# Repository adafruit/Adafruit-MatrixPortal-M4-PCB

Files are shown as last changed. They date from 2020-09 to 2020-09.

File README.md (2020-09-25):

## Adafruit MatrixPortal M4 - CircuitPython Powered Internet Display PCB

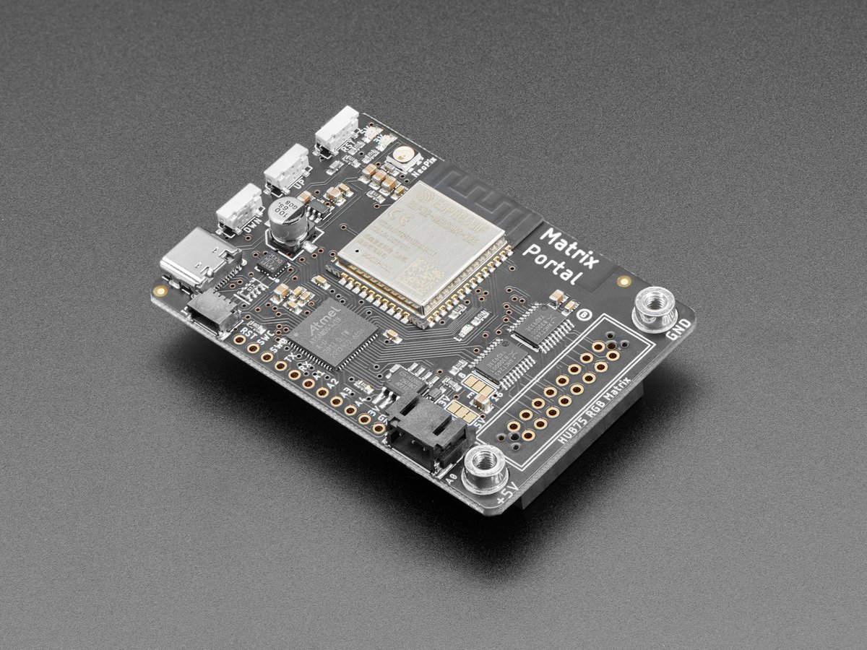
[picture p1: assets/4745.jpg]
<a href="http://www.adafruit.com/products/4745"><br/>
Click here to purchase one from the Adafruit shop</a>

PCB files for the Adafruit MatrixPortal M4 - CircuitPython Powered Internet Display. 

Format is EagleCAD schematic and board layout
* https://www.adafruit.com/product/4745

### Description

Folks love our [wide selection of RGB matrices](https://www.adafruit.com/category/327) and accessories, for making custom colorful LED displays... and our RGB Matrix Shields and FeatherWings can be quickly soldered together to make the wiring much easier. But what if we made it even easier than that? **Like, no solder, no wiring, just instant plug-and-play?** Dream no more - with the **Adafruit Matrix Portal add-on for RGB Matrices**, there's never been an easier way to create powerful Internet-connected LED displays.

Plug directly into the back of [any HUB-75 compatible display (all the ones we stock will work) from 16x32 up to 64x64](https://www.adafruit.com/category/327)! Use the included screws to attach the power cable to the power plugs with a common screwdriver, then power it with any USB C power supply. (For larger projects, power the matrices with a separate 5V power adapter)

Then code up your project in [CircuitPython](https://learn.adafruit.com/rgb-led-matrices-matrix-panels-with-circuitpython) or [Arduino](https://learn.adafruit.com/adafruit-protomatter-rgb-matrix-library), our Protomatter matrix library works great on the SAMD51 chipset, knowing that you've got the wiring and level shifting all handled. Here's what you get:

 * **ATSAMD51J19 Cortex M4 processor**, 512KB flash, 192K of SRAM, with full Arduino or CircuitPython support
 * **ESP32 WiFi co-processor** with TLS support and SPI interface to the M4, with full Arduino or CircuitPython support
 * **USB Type C** connector for data and power connectivity
 * [**I2C STEMMA QT connector** for plug-n-play use of any of our STEMMA QT devices or sensors](https://www.adafruit.com/category/620) can also be used with [any Grove I2C devices using this adapter cable](https://www.adafruit.com/product/4528))
 * **JST 3-pin connector** that also has analog input/output, say for adding audio playback to projects
 * **LIS3DH accelerometer** for digital sand projects or detecting taps/orientation.
 * **GPIO breakouts** including 4 analog outputs with PWM and SPI support for adding other hardware.
 * **Address E line jumper** for use with 64x64 matrices (check your matrix to see which pin is used for address E!
 * **Two user interface buttons** + one reset button
 * **Indicator NeoPixel** and red LED
 * **Green power indicator LEDs** for both 3V and 5V power
 * **2x10 socket connector** fits snugly into 2x8 HUB75 ports without worrying about 'off by one' errors.

The Matrix Portal uses an ATMEL (Microchip) ATSAMD51J19, and an Espressif ESP32 Wi-Fi coprocessor with TLS/SSL support built-in. The M4 and ESP32 are a great couple - and each bring their own strengths to this board. The SAMD51 M4 has native USB so it can show up like a disk drive, act as a MIDI or HID keyboard/mouse, and of course bootload and debug over a serial port. It also has DACs, ADC, PWM, and tons of GPIO, so it can handle the high speed updating of the RGB matrix.

Meanwhile, the ESP32 has secure WiFi capabilities, and plenty of Flash and RAM to buffer sockets. By letting the ESP32 focus on the complex TLS/SSL computation and socket buffering, it frees up the SAMD51 to act as the user interface. You get a great programming experience thanks to the native USB with files available for drag-n-drop, and you don't have to spend a ton of processor time and memory to do SSL encryption/decryption and certificate management. It's the best of both worlds!

Comes with one fully-programmed and assembled MatrixPortal, preprogrammed with a rainbow digital sand demo for 32x64 LED matrices.

### License

Adafruit invests time and resources providing this open source design, please support Adafruit and open-source hardware by purchasing products from [Adafruit](https://www.adafruit.com)!

Designed by Limor Fried/Ladyada for Adafruit Industries.

Creative Commons Attribution/Share-Alike, all text above must be included in any redistribution. 
See license.txt for additional details.

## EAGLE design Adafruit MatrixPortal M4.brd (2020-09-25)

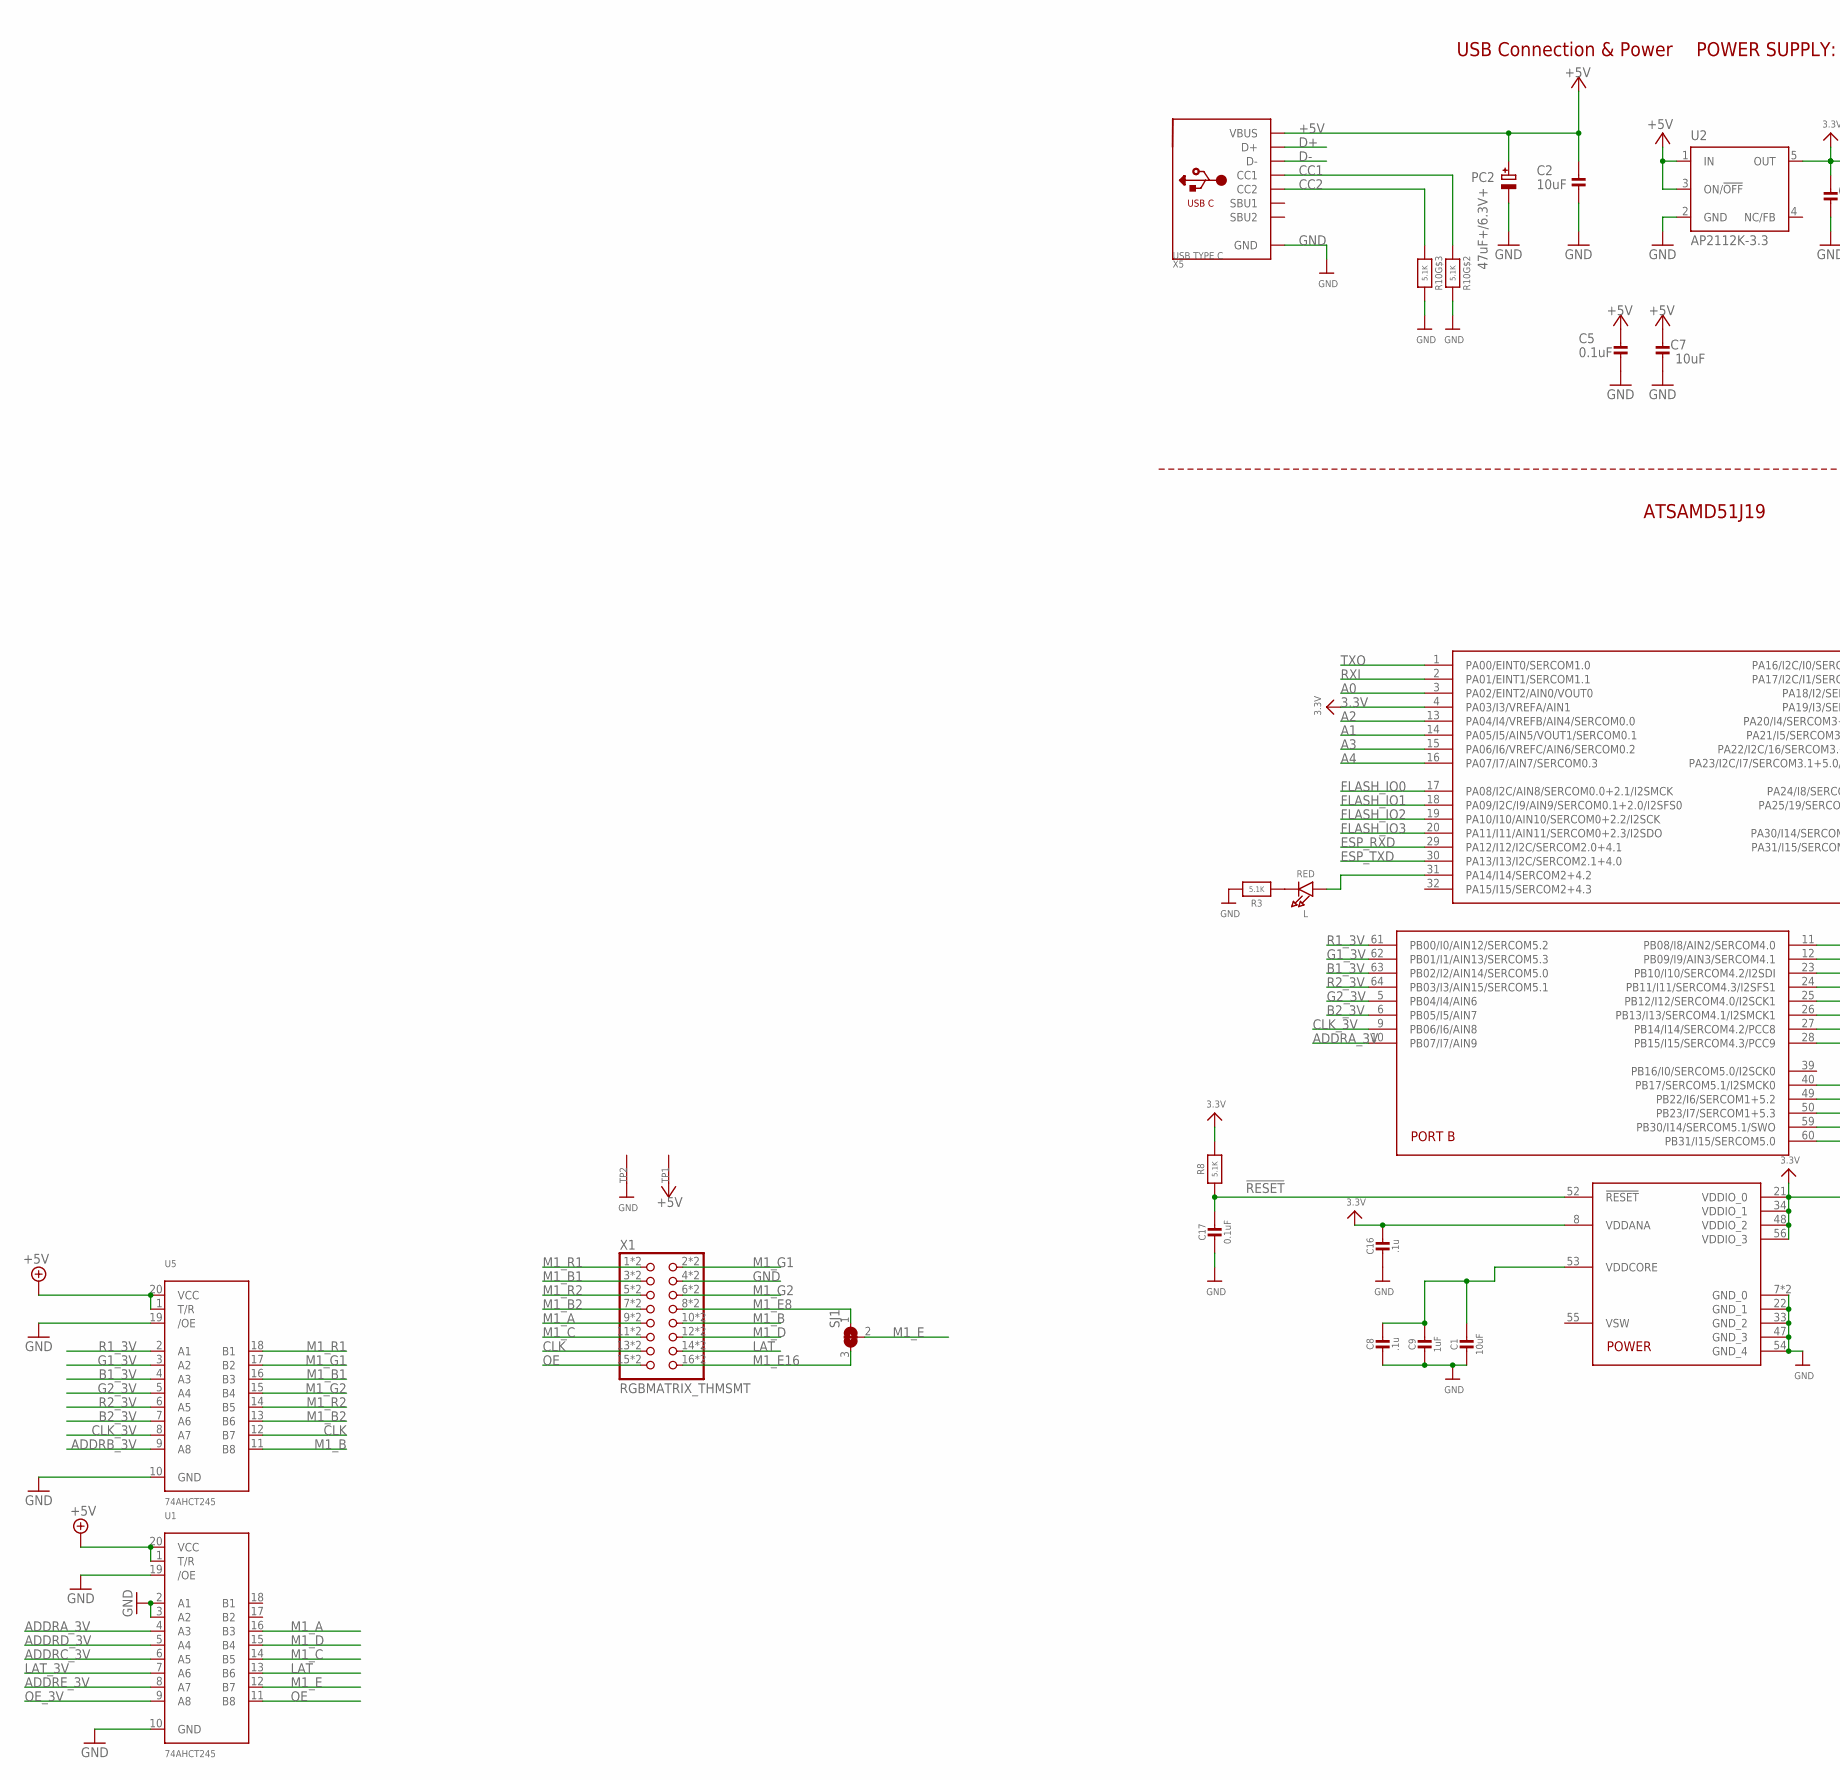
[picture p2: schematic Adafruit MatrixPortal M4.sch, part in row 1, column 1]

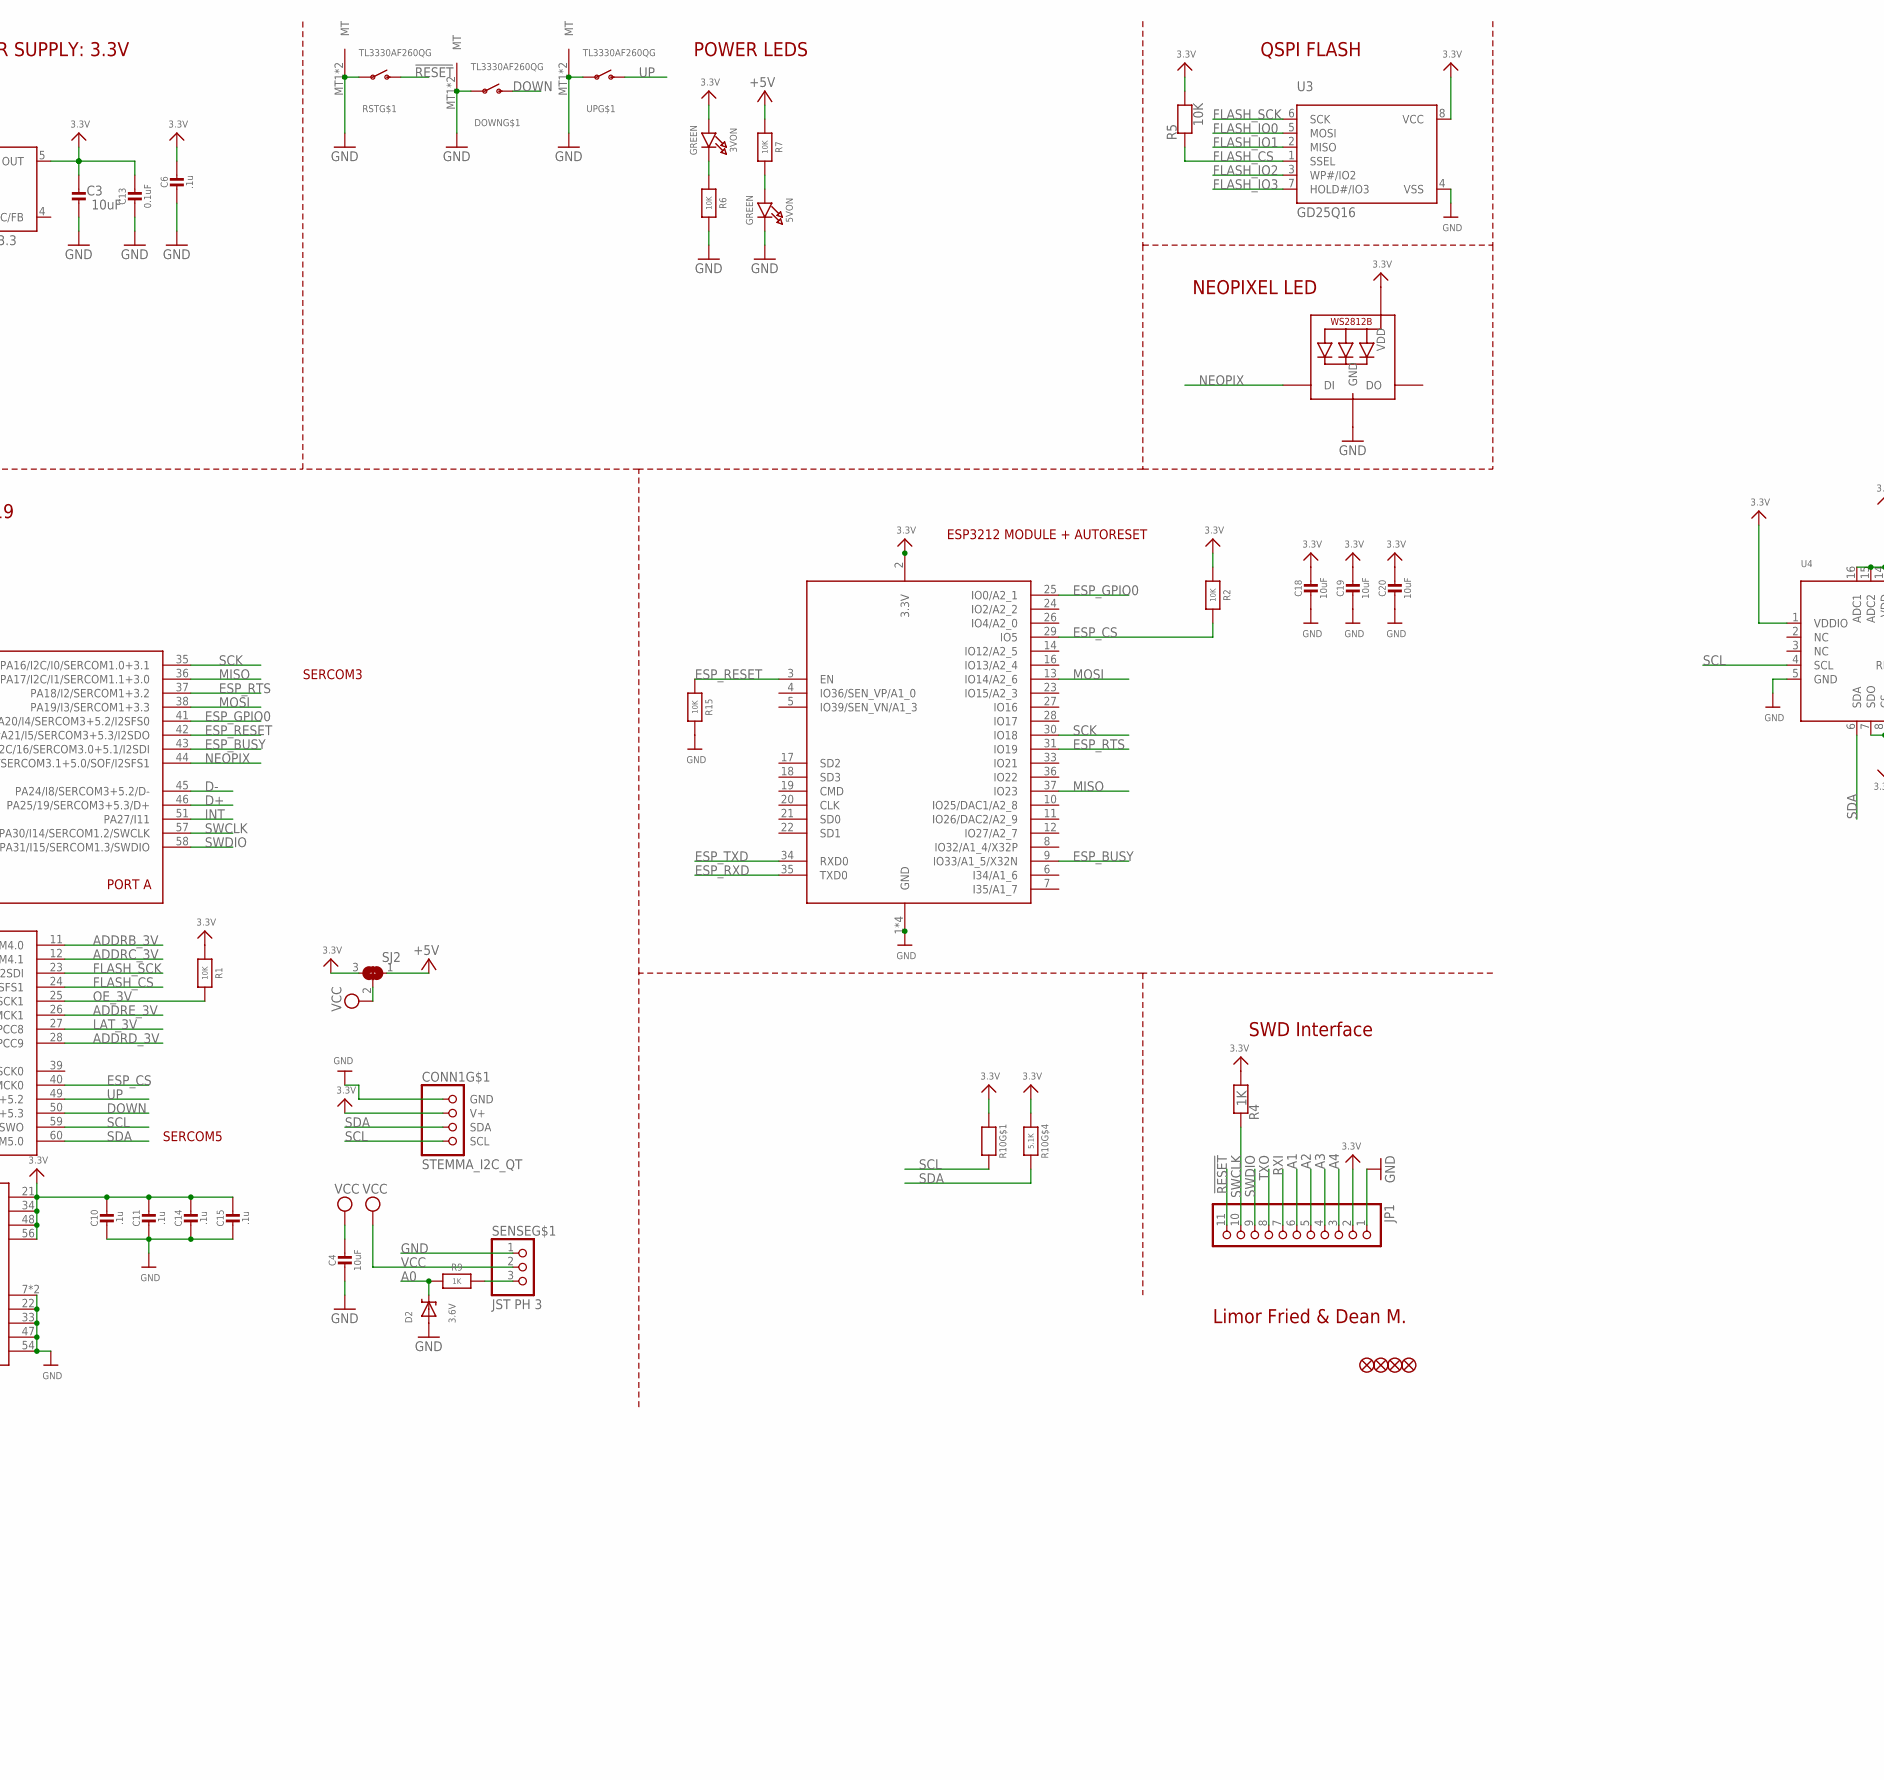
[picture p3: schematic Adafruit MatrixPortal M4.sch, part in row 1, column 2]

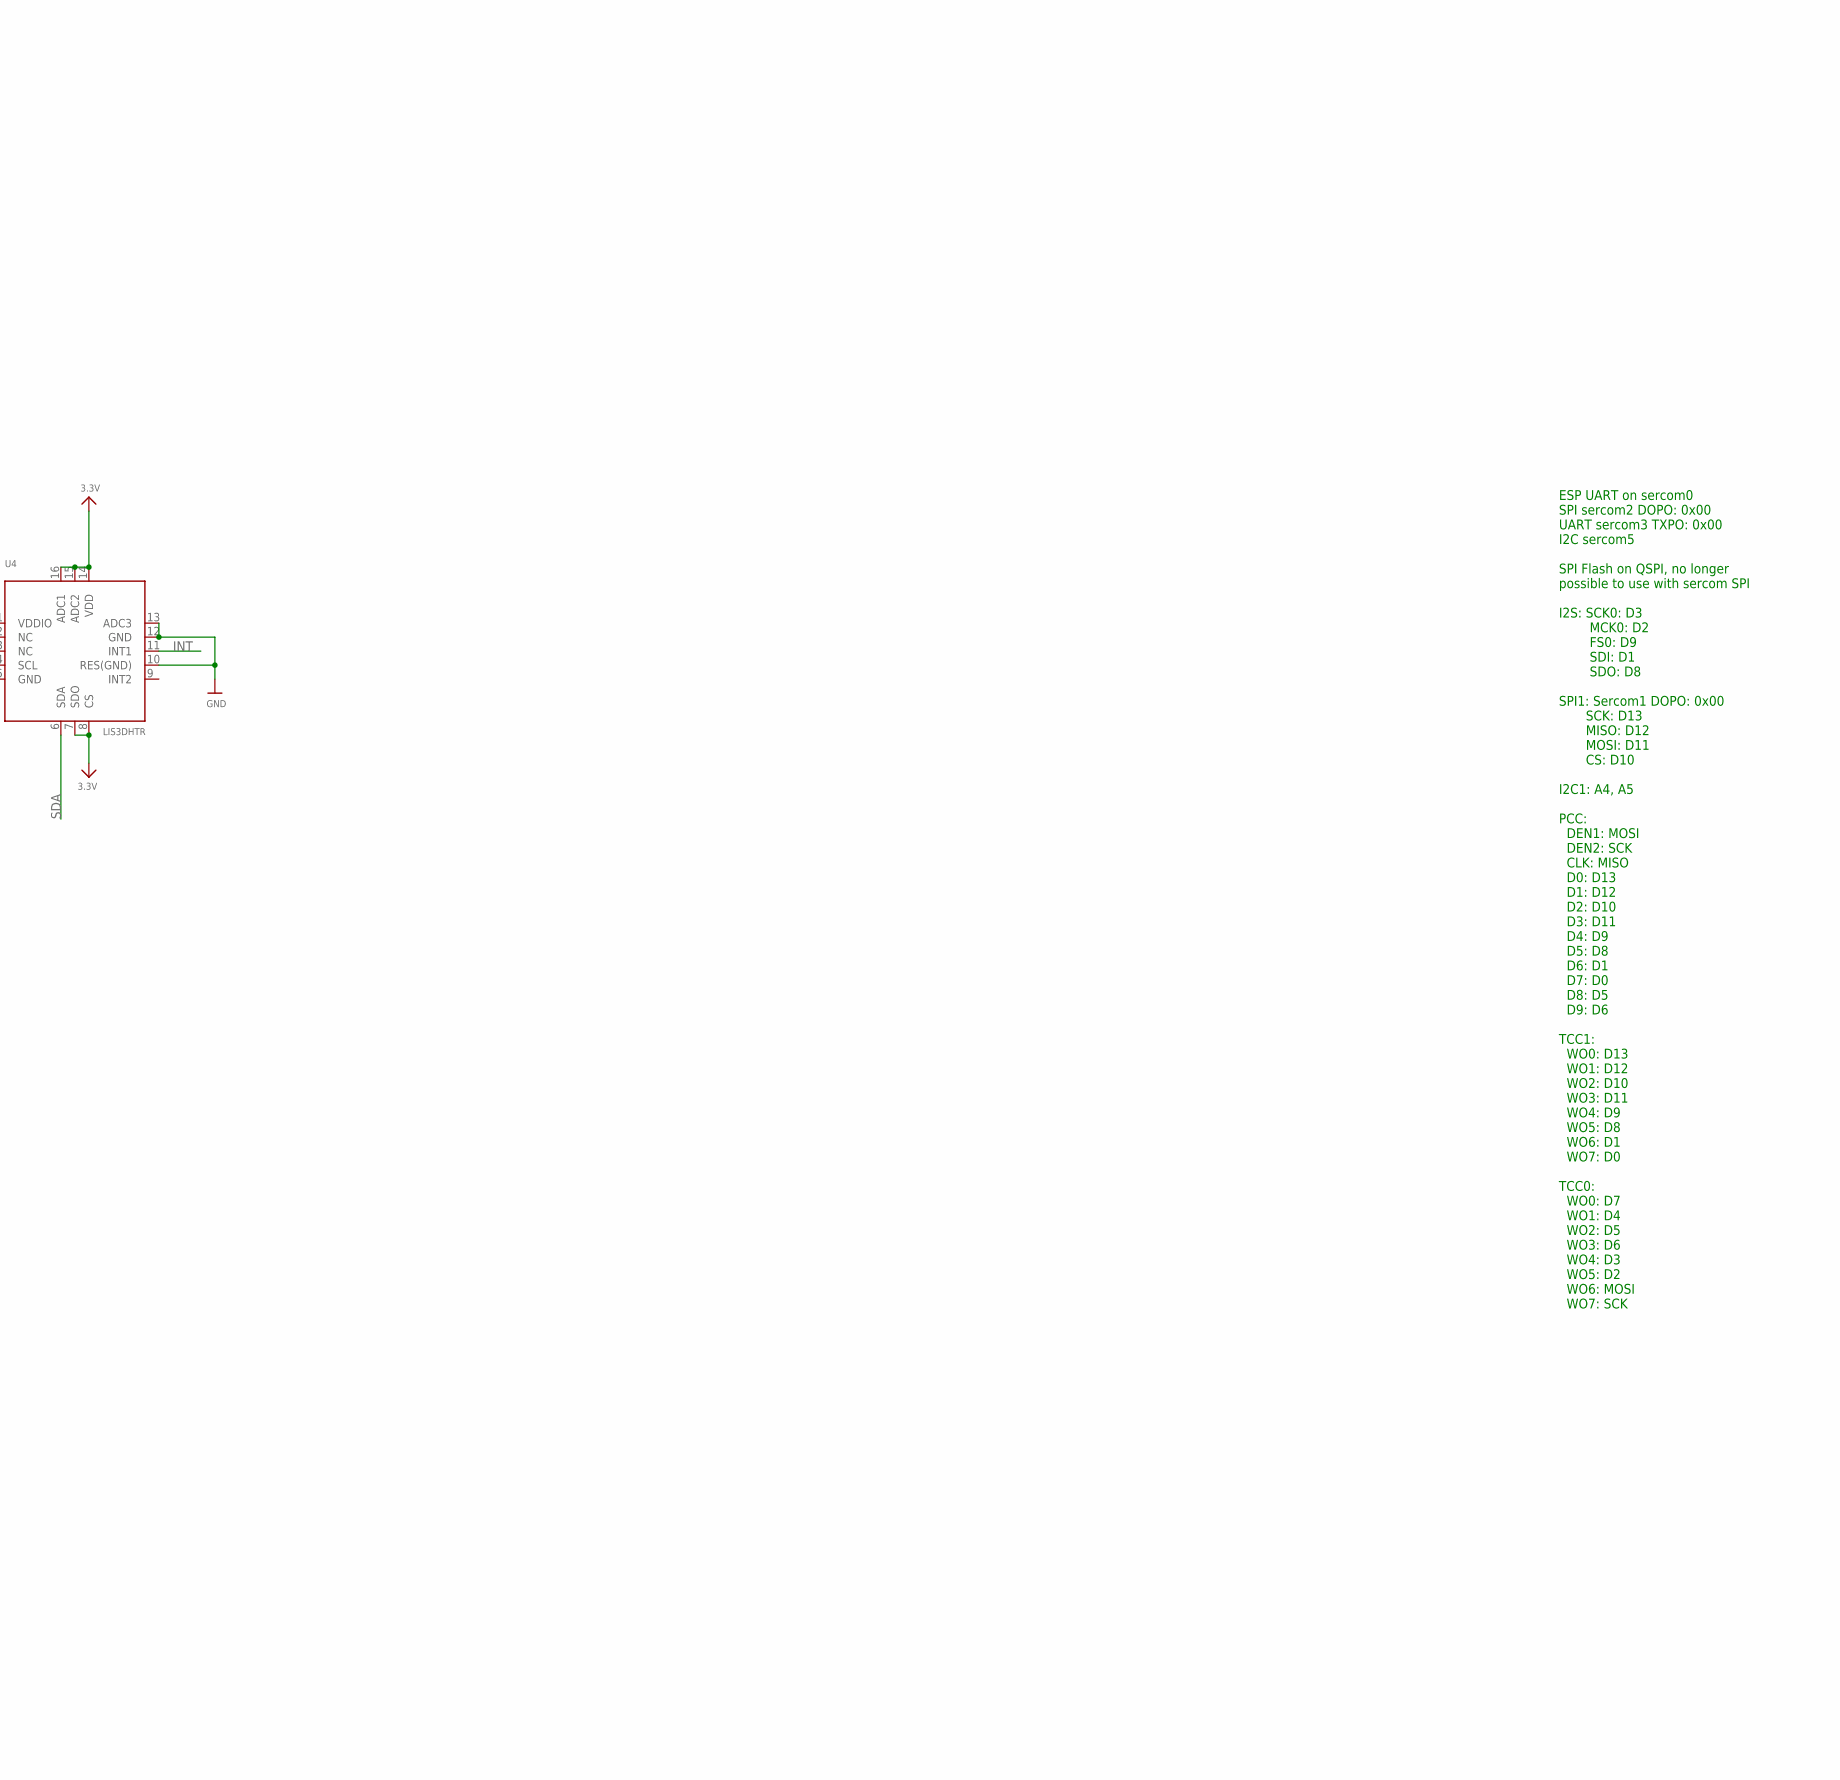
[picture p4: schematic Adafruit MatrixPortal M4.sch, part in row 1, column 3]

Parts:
3VON, 5VON: GREEN; CHIPLED_0805_NOOUTLINE
C1, C2, C3, C4, C7, C18, C19, C20: 10uF; 0805-NO
C5, C13, C17: 0.1uF; 0603-NO
C6, C8, C10, C11, C14, C15, C16: .1u; 0603-NO
C9: 1uF; 0603-NO
CONN1: STEMMA_I2C_QT; JST_SH4
D2: 3.6V; SOD-323
DOWN: TL3330AF260QG; SPST_TACTILE_RA
FID1, FID2, FID3, FID4: FIDUCIAL_1MM
JP1: HEADER-1X11; 1X11_ROUND
L: RED; CHIPLED_0603_NOOUTLINE
LED1: WS2812B3535; LED3535
PC2: 47uF+/6.3V+; PANASONIC_D
R1, R2, R5, R6, R7, R15: 10K; 0603-NO
R3, R8: 5.1K; 0603-NO
R4, R9: 1K; 0603-NO
R10: 5.1K; RESPACK_4X0603
RST: TL3330AF260QG; SPST_TACTILE_RA
SENSE: JST PH 3; JSTPH3
SJ1, SJ2: SOLDERJUMPER_2WAY; SOLDERJUMPER_2WAY_OPEN_NOPASTE
TP1, TP2: SEWTAP_SMTNUTM3; SMT_NUT_3MM
U1, U5: 74AHCT245; TSSOP20
U2: AP2112K-3.3; SOT23-DBV
U3: GD25Q16; SOIC8_208MIL
U4: LIS3DHTR; LGA16_3X3MM
U$1: ATSAMD51J19; PQFN64-1
UP: TL3330AF260QG; SPST_TACTILE_RA
X1: RGBMATRIX_THMSMT; 2X08_SMTTHM_RGBMATRIX
X5: USB TYPE C; USB_C_CUSB31-CFM2AX-01-X
X6: ESP32_WROOM32; WROOM32

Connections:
3.3V: 3VON.A, C3.2, C6.2, C10.2, C11.2, C13.1, C14.2, C15.2, C16.2, C18.1, C19.1, C20.1, CONN1.2 (V+), JP1.2, LED1.2 (VDD), R1.1, R2.1, R4.2, R5.2, R8.2, R10.1, R10.4 (1), SJ2.3, U2.5 (OUT), U3.8 (VCC), U4.1 (VDDIO), U4.7 (SDO), U4.8 (CS), U4.14 (VDD), U4.15 (ADC2), U4.16 (ADC1), U$1.4 (PA03/I3/VREFA/AIN1), U$1.8 (VDDANA), U$1.21 (VDDIO_0), U$1.34 (VDDIO_1), U$1.48 (VDDIO_2), U$1.56 (VDDIO_3), X6.2 (3.3V)
!RESET: C17.2, JP1.11, R8.1, RST.2 (S), U$1.52 (!RESET)
+5V: C2.2, C5.2, C7.2, PC2.+, R7.1, SJ2.1, TP1.P$1, U1.1 (T/R), U1.20 (VCC), U2.1 (IN), U2.3 (ON/!OFF), U5.1 (T/R), U5.20 (VCC), X5.A4B9 (VBUS), X5.B4A9 (VBUS)
A0: D2.C, R9.2, U$1.3 (PA02/EINT2/AIN0/VOUT0)
A0_JST: R9.1, SENSE.3
A1: JP1.6, U$1.14 (PA05/I5/AIN5/VOUT1/SERCOM0.1)
A2: JP1.5, U$1.13 (PA04/I4/VREFB/AIN4/SERCOM0.0)
A3: JP1.4, U$1.15 (PA06/I6/VREFC/AIN6/SERCOM0.2)
A4: JP1.3, U$1.16 (PA07/I7/AIN7/SERCOM0.3)
ADDRA_3V: U1.4 (A3), U$1.10 (PB07/I7/AIN9)
ADDRB_3V: U5.9 (A8), U$1.11 (PB08/I8/AIN2/SERCOM4.0)
ADDRC_3V: U1.6 (A5), U$1.12 (PB09/I9/AIN3/SERCOM4.1)
ADDRD_3V: U1.5 (A4), U$1.28 (PB15/I15/SERCOM4.3/PCC9)
ADDRE_3V: U1.8 (A7), U$1.26 (PB13/I13/SERCOM4.1/I2SMCK1)
B1_3V: U5.4 (A3), U$1.63 (PB02/I2/AIN14/SERCOM5.0)
B2_3V: U5.7 (A6), U$1.6 (PB05/I5/AIN7)
CC1: R10.2 (1), X5.A5 (CC1)
CC2: R10.3 (1), X5.B5 (CC2)
CLK: U5.12 (B7), X1.13, X1.13S (13)
CLK_3V: U5.8 (A7), U$1.9 (PB06/I6/AIN8)
D+: U$1.46 (PA25/19/SERCOM3+5.3/D+), X5.A6 (D+), X5.B6 (D+)
D-: U$1.45 (PA24/I8/SERCOM3+5.2/D-), X5.A7 (D-), X5.B7 (D-)
DOWN: DOWN.2 (S), U$1.50 (PB23/I7/SERCOM1+5.3)
ESP_BUSY: U$1.43 (PA22/I2C/16/SERCOM3.0+5.1/I2SDI), X6.9 (IO33/A1_5/X32N)
ESP_CS: R2.2, U$1.40 (PB17/SERCOM5.1/I2SMCK0), X6.29 (IO5)
ESP_GPIO0: U$1.41 (PA20/I4/SERCOM3+5.2/I2SFS0), X6.25 (IO0/A2_1)
ESP_RESET: R15.1, U$1.42 (PA21/I5/SERCOM3+5.3/I2SDO), X6.3 (EN)
ESP_RTS: U$1.37 (PA18/I2/SERCOM1+3.2), X6.31 (IO19)
ESP_RXD: U$1.29 (PA12/I12/I2C/SERCOM2.0+4.1), X6.35 (TXD0)
ESP_TXD: U$1.30 (PA13/I13/I2C/SERCOM2.1+4.0), X6.34 (RXD0)
FLASH_CS: R5.1, U3.1 (SSEL), U$1.24 (PB11/I11/SERCOM4.3/I2SFS1)
FLASH_IO0: U3.5 (MOSI), U$1.17 (PA08/I2C/AIN8/SERCOM0.0+2.1/I2SMCK)
FLASH_IO1: U3.2 (MISO), U$1.18 (PA09/I2C/I9/AIN9/SERCOM0.1+2.0/I2SFS0)
FLASH_IO2: U3.3 (WP#/IO2), U$1.19 (PA10/I10/AIN10/SERCOM0+2.2/I2SCK)
FLASH_IO3: U3.7 (HOLD#/IO3), U$1.20 (PA11/I11/AIN11/SERCOM0+2.3/I2SDO)
FLASH_SCK: U3.6 (SCK), U$1.23 (PB10/I10/SERCOM4.2/I2SDI)
G1_3V: U5.3 (A2), U$1.62 (PB01/I1/AIN13/SERCOM5.3)
G2_3V: U5.5 (A4), U$1.5 (PB04/I4/AIN6)
GND: 5VON.C, C1.2, C2.1, C3.1, C4.2, C5.1, C6.1, C7.1, C8.1, C9.2, C10.1, C11.1, C13.2, C14.1, C15.1, C16.1, C17.1, C18.2, C19.2, C20.2, CONN1.1 (GND), D2.A, DOWN.1, DOWN.MT1 (MT), DOWN.MT2 (MT), JP1.1, LED1.4 (GND), PC2.-, R3.2, R6.2, R10.6 (2), R10.7 (2), R15.2, RST.1, RST.MT1 (MT), RST.MT2 (MT), SENSE.1, TP2.P$1, U1.2 (A1), U1.3 (A2), U1.10 (GND), U1.19 (/OE), U2.2 (GND), U3.4 (VSS), U4.5 (GND), U4.10 (RES(GND)), U4.12 (GND), U4.13 (ADC3), U5.10 (GND), U5.19 (/OE), U$1.7 (GND_0), U$1.22 (GND_1), U$1.33 (GND_2), U$1.47 (GND_3), U$1.54 (GND_4), U$1.EXP (GND_0), UP.1, UP.MT1 (MT), UP.MT2 (MT), X1.4, X1.4S (4), X5.A1B12 (GND), X5.B1A12 (GND), X6.1 (GND), X6.15 (GND), X6.38 (GND), X6.P$1 (GND)
INT: U4.11 (INT1), U$1.51 (PA27/I11)
LAT: U1.13 (B6), X1.14, X1.14S (14)
LAT_3V: U1.7 (A6), U$1.27 (PB14/I14/SERCOM4.2/PCC8)
M1_A: U1.16 (B3), X1.9, X1.9S (9)
M1_B: U5.11 (B8), X1.10, X1.10S (10)
M1_B1: U5.16 (B3), X1.3, X1.3S (3)
M1_B2: U5.13 (B6), X1.7, X1.7S (7)
M1_C: U1.14 (B5), X1.11, X1.11S (11)
M1_D: U1.15 (B4), X1.12, X1.12S (12)
M1_E: SJ1.2, U1.12 (B7)
M1_E8: SJ1.1, X1.8, X1.8S (8)
M1_E16: SJ1.3, X1.16, X1.16S (16)
M1_G1: U5.17 (B2), X1.2, X1.2S (2)
M1_G2: U5.15 (B4), X1.6, X1.6S (6)
M1_R1: U5.18 (B1), X1.1, X1.1S (1)
M1_R2: U5.14 (B5), X1.5, X1.5S (5)
MISO: U$1.36 (PA17/I2C/I1/SERCOM1.1+3.0), X6.37 (IO23)
MOSI: U$1.38 (PA19/I3/SERCOM1+3.3), X6.13 (IO14/A2_6)
unnamed: 5VON.A, R7.2
unnamed: 3VON.C, R6.1
unnamed: L.A, U$1.31 (PA14/I14/SERCOM2+4.2)
unnamed: L.C, R3.1
NEOPIX: LED1.1 (DI), U$1.44 (PA23/I2C/I7/SERCOM3.1+5.0/SOF/I2SFS1)
OE: U1.11 (B8), X1.15, X1.15S (15)
OE_3V: R1.2, U1.9 (A8), U$1.25 (PB12/I12/SERCOM4.0/I2SCK1)
R1_3V: U5.2 (A1), U$1.61 (PB00/I0/AIN12/SERCOM5.2)
R2_3V: U5.6 (A5), U$1.64 (PB03/I3/AIN15/SERCOM5.1)
RXI: JP1.7, U$1.2 (PA01/EINT1/SERCOM1.1)
SCK: U$1.35 (PA16/I2C/I0/SERCOM1.0+3.1), X6.30 (IO18)
SCL: CONN1.4 (SCL), R10.8 (2), U4.4 (SCL), U$1.59 (PB30/I14/SERCOM5.1/SWO)
SDA: CONN1.3 (SDA), R10.5 (2), U4.6 (SDA), U$1.60 (PB31/I15/SERCOM5.0)
SWCLK: JP1.10, R4.1, U$1.57 (PA30/I14/SERCOM1.2/SWCLK)
SWDIO: JP1.9, U$1.58 (PA31/I15/SERCOM1.3/SWDIO)
TXO: JP1.8, U$1.1 (PA00/EINT0/SERCOM1.0)
UP: U$1.49 (PB22/I6/SERCOM1+5.2), UP.2 (S)
VCC: C4.1, SENSE.2, SJ2.2
VDDCORE: C1.1, C8.2, C9.1, U$1.53 (VDDCORE)

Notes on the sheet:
Limor Fried & Dean M.
USB Connection & Power
POWER SUPPLY: 3.3V
POWER LEDS
ATSAMD51J19
NEOPIXEL LED
QSPI FLASH
SWD Interface
ESP UART on sercom0 SPI sercom2 DOPO: 0x00 UART sercom3 TXPO: 0x00 I2C sercom5 SPI Flash on QSPI, no longer possible to use with sercom SPI I2S: SCK0: D3 MCK0: D2 FS0: D9 SDI: D1 SDO: D8 SPI1: Sercom1 DOPO: 0x00 SCK: D13 MISO: D12 MOSI: D11 CS: D10 I2C1: A4, A5 PCC: DEN1: MOSI DEN2: SCK CLK: MISO D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
ESP3212 MODULE + AUTORESET
SERCOM5
SERCOM3

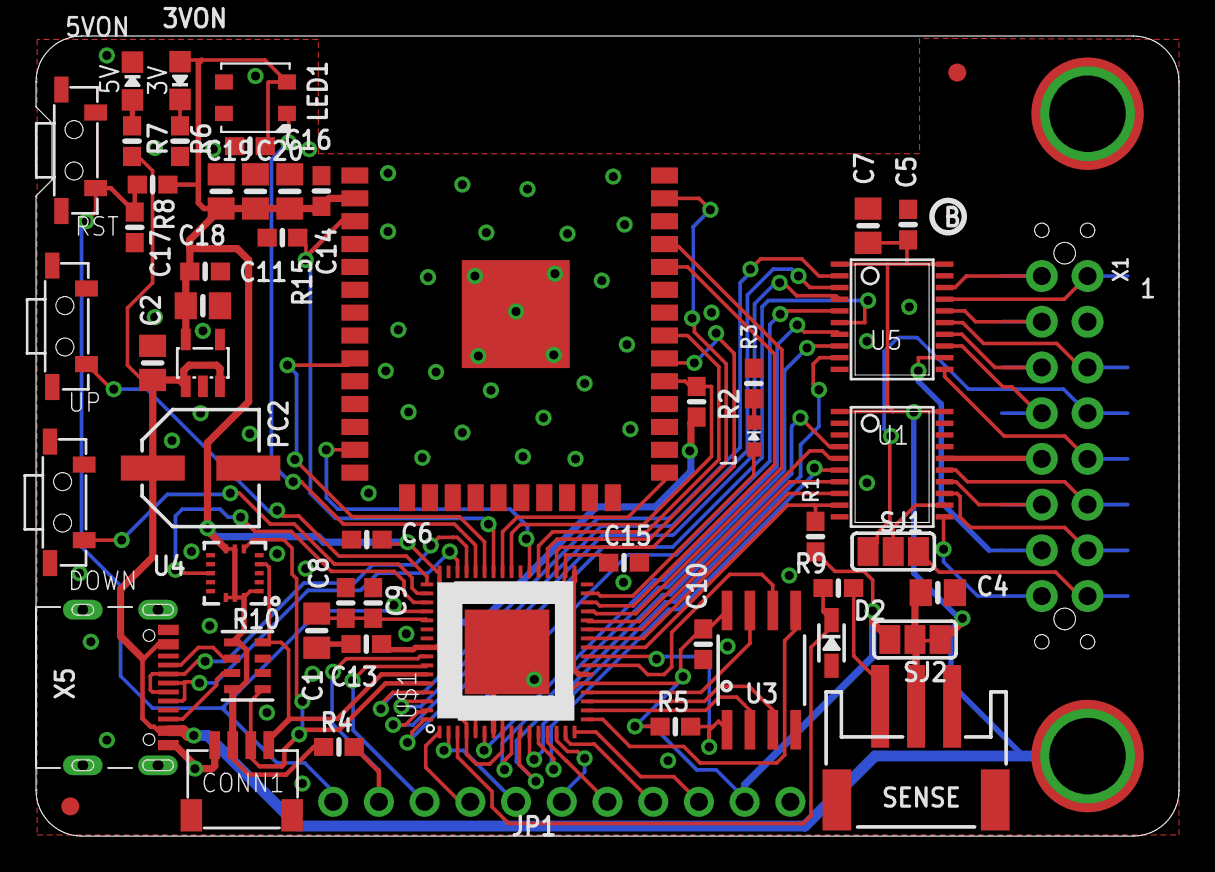
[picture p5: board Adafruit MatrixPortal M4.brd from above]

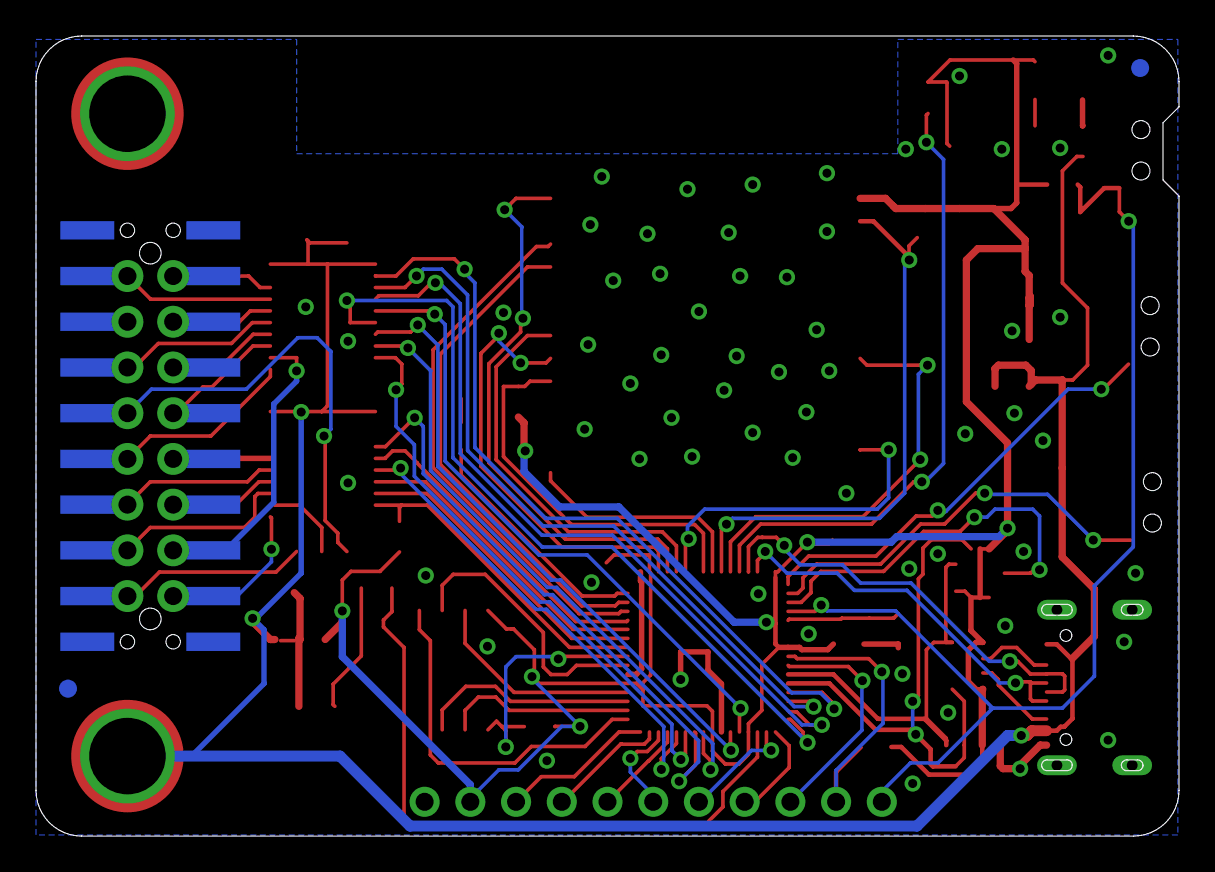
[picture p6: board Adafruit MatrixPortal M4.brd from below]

Board: 2 copper layers, 63.5 x 44.5 mm, 62 parts (3 on the bottom side), 76 nets.

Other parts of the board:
U$41: MATRIXPORTAL_BOT
U$44: PCBFEAT-REV-040
U$45: MATRIXPORTAL_TOP

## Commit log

2020-09-25 Added board and schematic files and template
    [Adafruit MatrixPortal M4.brd, Adafruit MatrixPortal M4.sch]
2020-09-25 Updated dimensions
    [Adafruit MatrixPortal M4.brd]
2020-09-25 Cleaned up MatrixPortal Schematic
    [Adafruit MatrixPortal M4.sch]

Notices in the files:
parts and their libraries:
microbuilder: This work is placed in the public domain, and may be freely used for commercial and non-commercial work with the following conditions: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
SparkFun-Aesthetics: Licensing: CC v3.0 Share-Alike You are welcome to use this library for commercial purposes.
